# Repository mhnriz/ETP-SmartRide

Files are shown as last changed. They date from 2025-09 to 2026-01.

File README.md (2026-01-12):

# ETP-SmartRide: Smart Transit & Monitoring System
**Status:** Functional Prototype Handed Over
**Date:** January 2026

## 📌 Project Overview
ETP-SmartRide is an IoT-based transit system designed to improve bus efficiency and passenger experience. The system integrates real-time seat occupancy tracking, GPS location monitoring, and a Smart Bus Stop ETA display. 

The project was executed in two phases:
1. **Phase 1 (Planning):** Research, Power Budgeting, and Circuit Drafting.
2. **Phase 2 (Execution):** Hardware integration, ESP-NOW communication, and Firebase Cloud syncing.

## ⚙️ System Architecture
Due to hardware logistics, the current prototype uses a **Modular ESP32 Mesh** rather than a Raspberry Pi master.

* **Master Node (ESP32):** Acts as the Cloud Gateway. It fetches booking data from Firebase via WiFi and broadcasts seat status to nodes.
* **Slave Nodes (ESP32):** Distributed across the bus. Each node manages 4 seats, controlling bi-color LEDs and ultrasonic sensors.
* **Communication:** Internal data is sent via **ESP-NOW** for low-latency, while external data uses **HTTPS/Firebase**.
* **Bus Stop Display:** Uses the same Master circuit to fetch ETA data and output to a 22" monitor.

## 🔋 Hardware & Power Specifications
The system is designed for mobility and sustainability:
- **Power Source:** 100W Monocrystalline Solar Panel [B-18].
- **Storage:** 15AH 12V AGM Solar Battery [B-20].
- **Regulation:** LM2596 Buck-down modules regulated to 5V for logic circuits.
- **Enclosures:** Custom 3D-printed PLA housings.

> **⚠️ HANDOVER NOTE:** All LM2596 buck converters must be verified with a multimeter for stable 5V output before connecting the ESP32 or Pi.

## 📂 Repository Structure
- `/firmware`: Contains `.ino` files for the Bus Master, Bus Stop, and Seat Nodes.
- `/hardware`: Contains the archived KiCad project files (`.zip`) and PDF schematics.
- `/hardware/parts_list.md`: Full Bill of Materials (BOM) with IDs.
- `/docs`: Power budgeting, initial planning documents, and architecture diagrams.
- `HANDOVER.md`: Technical guide for the incoming 8-month team.

## 🚀 Quick Start (Prototype Mode)
1. **Configure WiFi:** Update `ssid` and `password` in the `master_esp32.ino`.
2. **Firebase:** Ensure your `FIREBASE_TOKEN` and URL match your Firestore instance.
3. **Flash Nodes:** Flash the `slave_node.ino` to the respective ESP32s using the MAC addresses listed in the Master code.

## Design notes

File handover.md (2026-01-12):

# 📝 Technical Handover Guide

## 1. Main Unit (Master) Integration
The Main Unit acts as the system Master, responsible for GPS tracking, LTE cloud communication, and managing the RS-485 bus to poll Sensor Nodes.

### ⚙️ Hardware Details
| Component | Function | Hardware Note |
| :--- | :--- | :--- |
| **Raspberry Pi 4** | System Controller | Main logic and UART management. |
| **A7670E Cat-1 HAT** | LTE Module | Cellular data transmission. |
| **NEO-6M GPS** | GPS Receiver | Real-time location tracking. |
| **MAX3485** | RS-485 Transceiver | Communication with Sensor Nodes. |
| **LM2596 Buck** | Power Regulator | Steps down bus voltage (12V) to 5V. |

### ⚠️ Power Logic & Safety
* **Calibration:** The LM2596 must be tuned to exactly **5V** BEFORE connecting to the Raspberry Pi 4.
* **Sensitivity:** The Raspberry Pi is highly sensitive to overvoltage. Always measure output with a multimeter before plugging in the Pi.
* **GPS Fix:** The NEO-6M requires a "Cold Start" which can take several minutes. Ensure the antenna has a clear line of sight to the sky.

---

## 2. Sensor Node (Slave) Integration
Each node monitors 4 seats, processes occupancy locally, and communicates with the Master via RS-485.

### 📊 The Bitmap System
To minimize data traffic, seat status is packed into a single byte (Bitmap):
* **Bit 0 (1):** Seat 1 (or 5, 9, etc.)
* **Bit 1 (2):** Seat 2
* **Bit 2 (4):** Seat 3
* **Bit 3 (8):** Seat 4
* **Example:** If Master sends `0110`, Seats 2 and 3 are marked as Booked.

### 📍 Pinout Reference (ESP32)
| Component | ESP32 Pin | Function | Hardware Note |
| :--- | :--- | :--- | :--- |
| **MAX3485 RO** | GPIO 17 | RXD2 | Connect to Receiver Output. |
| **MAX3485 DI** | GPIO 16 | TXD2 | Connect to Driver Input. |
| **MAX3485 RE/DE**| GPIO 2 | EN (Direction) | HIGH = Transmit, LOW = Receive. |
| **VL53L0X SDA** | GPIO 21 | I2C Data | All sensors share this line. |
| **VL53L0X SCL** | GPIO 22 | I2C Clock | All sensors share this line. |
| **XSHUT 1** | GPIO 18 | Reset 1 | Used to assign Address 0x30. |
| **XSHUT 2** | GPIO 19 | Reset 2 | Used to assign Address 0x31. |

---

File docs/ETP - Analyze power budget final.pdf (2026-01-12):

# Operating Scenario:

- 7AM to 7PM (12 operating hours)
- At least 5 total hours of sunlight
- based on local solar radiation data at UTP, Perak (Reference) (https://utpedia.utp.edu.my/id/eprint/13641/1/Final%20Dissertation.pdf)
- Assume solar power unit efficiency at 65%
- All component runs at 5V*

# Component Operating Characteristics for bus unit:

## RASPBERRY PI 4:

- Always active
- Estimated current: 1A

A7670E:
- TX every 10 seconds, assume TX takes 1 secs
- Estimated current:
- Idle: mA for 9 secs
- Active: 500mA for 1 secs
- Rare case: 2A, handle by 2200µ 25V capacitor
- Average: 77mA
- Reference (Section 5.4) (https://nostris.ee/pdf/A7670%20Series%20Hardware%20Design_V1.00.pdf)

## NodeMCU ESP-32:

- Always active
- Estimated current: 53mA
- Reference (Section 5.4) (https://www.espressif.com/sites/default/files/documentation/esp32_datasheet_en.pdf)

## Xiaomi Redmi Monitor RMMNT215NF:

- Always active
- current: 2A
- Voltage: 12A
- Reference (Similar product) (https://www.manualslib.com/manual/3883141/Xiaomi-Rmmnt27nf.html?page=12#manual)

## SFM-27 BUZZER:

- Active during bus stop, assume 2 minutes every 5 minutes, 4 pieces
- Always active
- Estimated current: 6mA
- Reference (Product descripton) (https://shopee.com.my/Buzzer-with-Wire-3-24V-SFM-27-2312-%28Continuous-Sound-Intermittent-Sound%29-i.82137098.11625621562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)

## NEO-6m:

- Always active
- Estimated current: 70mA
- Reference (Section 3.3) (https://content.u-blox.com/sites/default/files/products/documents/NEO-6_DataSheet_%28GPS.G6-HW-09005%29.pdf)

## MAX485:

- Always active
- Estimated current: 1.6mA

## MH-ET LIVE Scanner v3.0:

- Always active
- Estimated current: 20mA

## LED light:

- Active during bus stop, assume 2 minutes every 5 minutes, 4 pieces
- Estimated current:
- Active: 80mA (4 × 20mA) for 2 minutes
- Average:32mA
- Reference (Product description) (https://shopee.com.my/100PCS-LED-3mm-5mm-Round-Diffused-Matte-Water-Clear-Red-Blue-Green-Two-Color-Common-Anode-Cathode-LED-Diode-Light-Emitting-Diode-i.12432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)

## ToF sensor VL53L0XV2:

- Active during bus stop, assume 2 minutes every 5 minutes, 4 pieces (seat)+ 1 at door
- Estimated current:
- Active: 675mA (45 × 15 mA)
- Average: 270mA

# Component Operating Characteristics for bus stop unit:

## RASPBERRY PI 4:

- Always active
- Estimated current: 1A

A7670E:
- TX every 10 seconds, assume TX takes 1 secs
- Estimated current:
- Idle: mA for 9 secs
- Active: 500mA for 1 secs
- Rare case: 2A, handle by 2200µ 25V capacitor
- Average: 77mA
- Reference (Section 5.4) (https://nostris.ee/pdf/A7670%20Series%20Hardware%20Design_V1.00.pdf)

## Xiaomi Redmi Monitor RMMNT215NF:

- Always active
- current: 2A
- Voltage: 12A
- Reference (Similar product) (https://www.manualslib.com/manual/3883141/Xiaomi-Rmmnt27nf.html?page=12#manual)

# Daily Energy Consumption Estimate:

Module | Avg Current (mA) | Voltage (V) | Daily Runtime (h) | Energy (Wh/Day)
Bus Stop Unit | 3077 | 5 | 12 | 184.6
Bus Unit | 3291 | 5 | 12 | 197.3
Total | 6368 | 5 | 12 | 381.9

# Solar Power System Feasibility:

## Solar Panel:

- Maximum Power: 100W
- Voltage at Maximum Power: 18V
- Current at Max power: 5.56A
- Reference (Product description) (https://shopee.com.my/POWERMAS-20-Watt-20W-Monocrystalline-A-Grade-Solar-Panel-(Ready-Stock)-i.988475493.22643540091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)

## Estimated Daily Energy Harvest:

At 65% efficiency:
100W ×

65
100 × 5ℎ = 325Wℎ/day

## Battery:

- Bus unit:
- Total capacity: 15Ah 12 V nominal
- Bus stop unit
- Total capacity: 15mAh 12 V nominal

## System Analysis Conclusion:

Module | Daily energy need | Solar daily harvest | Daily Surplus | Battery capacity | Backup runtime (battery only)
Bus Unit | 197.3 Wh | 325 Wh | +127.7 Wh | 180 Wh | 0.91 days
Bus Stop Unit | 184.6 Wh | 325 Wh | +140.4 Wh | 180 Wh | 0.98 days

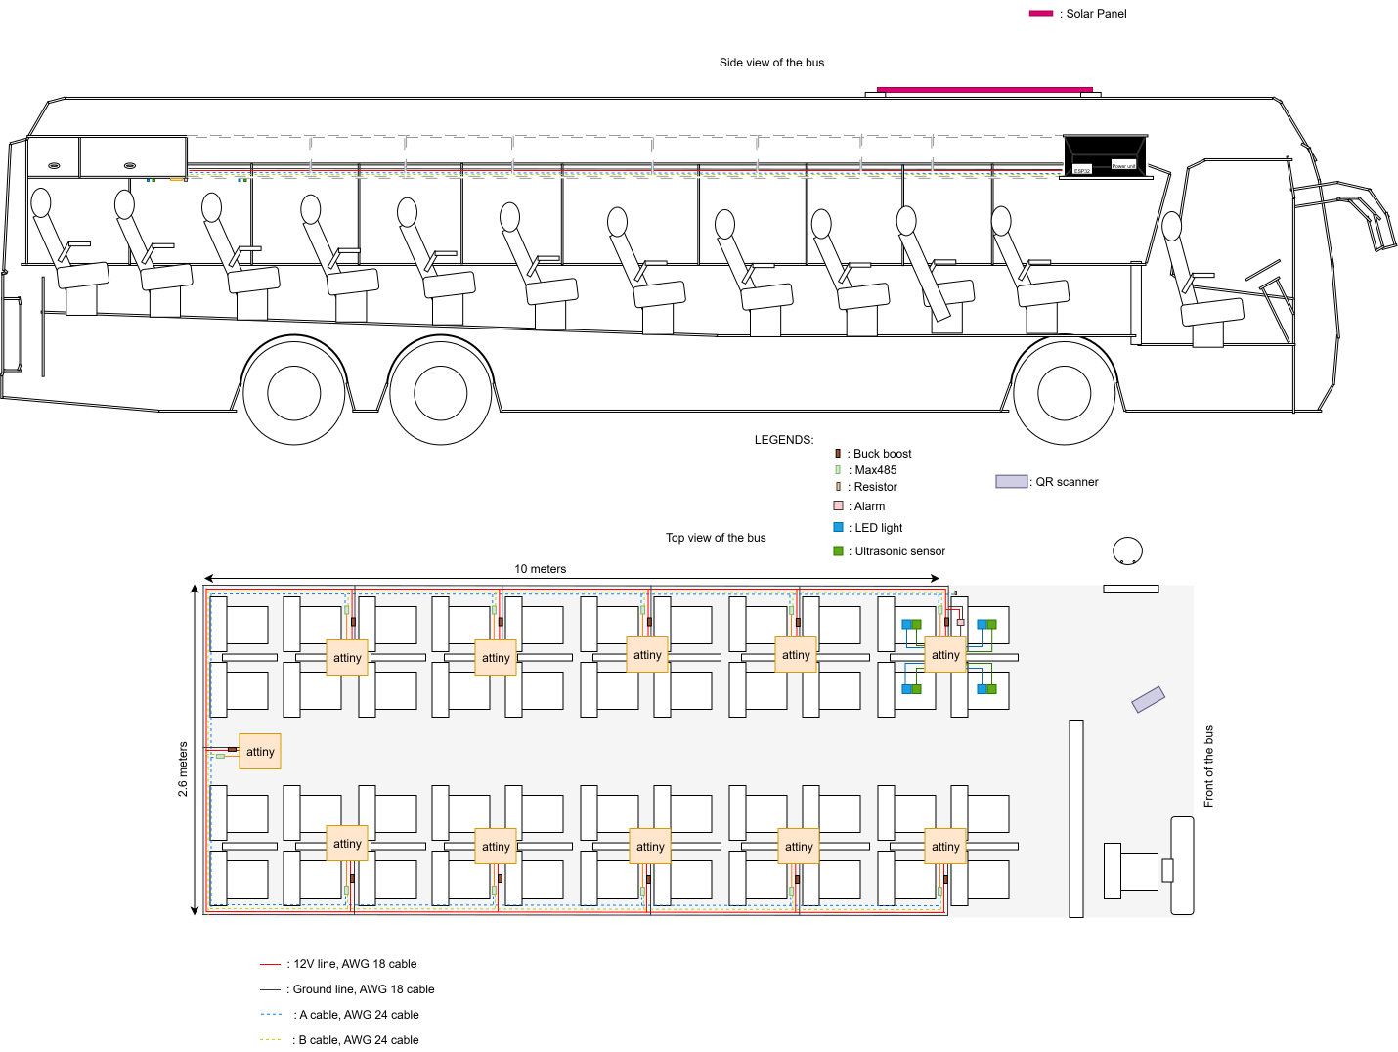
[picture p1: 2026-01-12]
docs/Bus_layout _overview.png

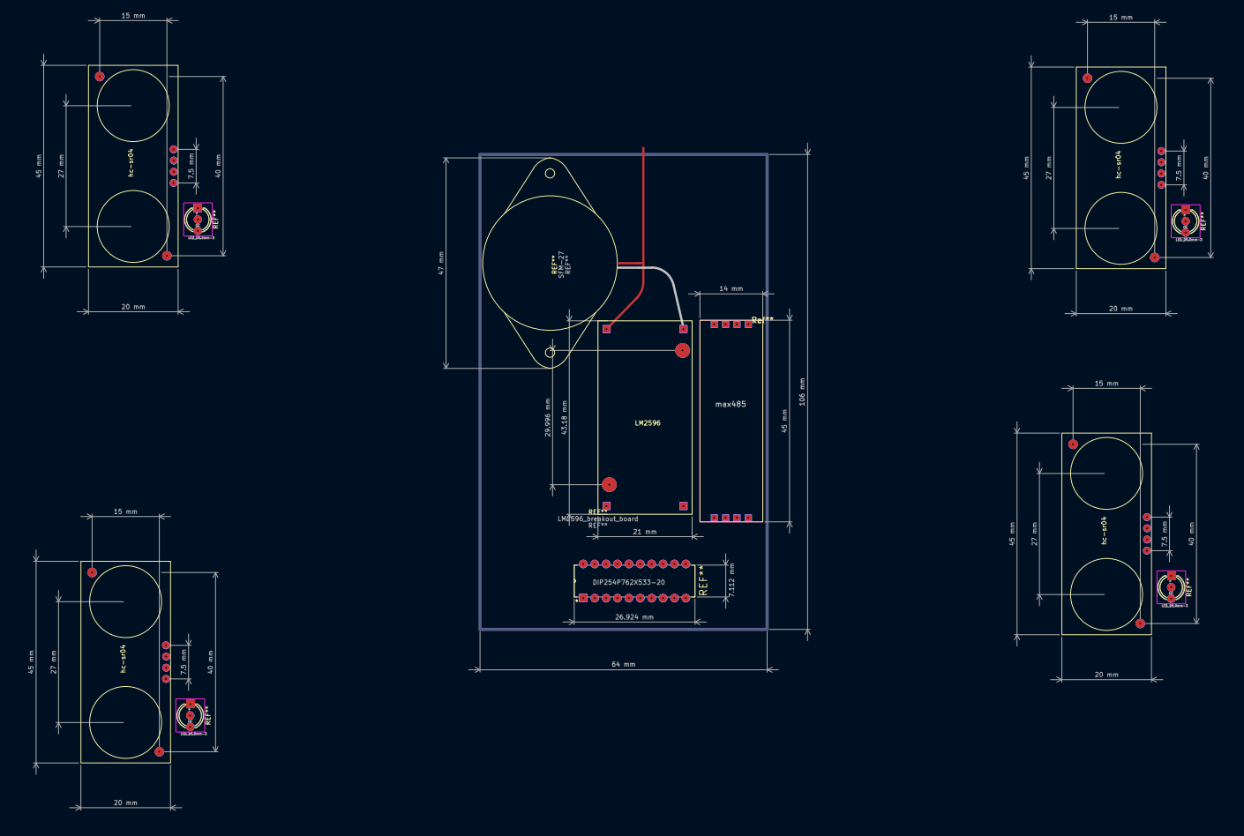
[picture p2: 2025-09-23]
hardware/bus_seat_unit/layout.png

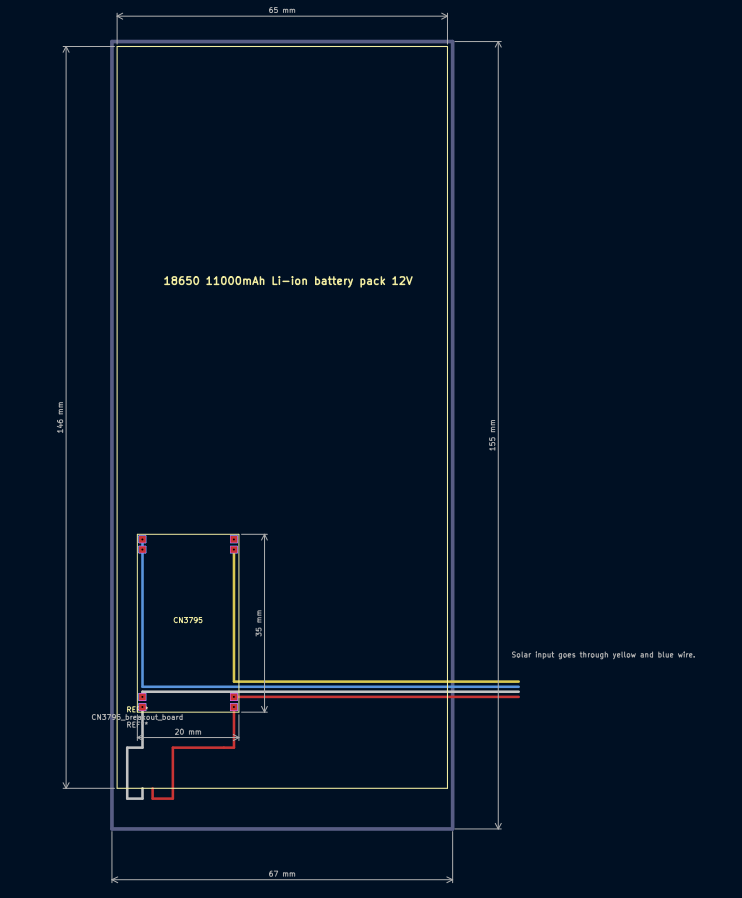
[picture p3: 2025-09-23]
hardware/bus_power_unit/layout.png

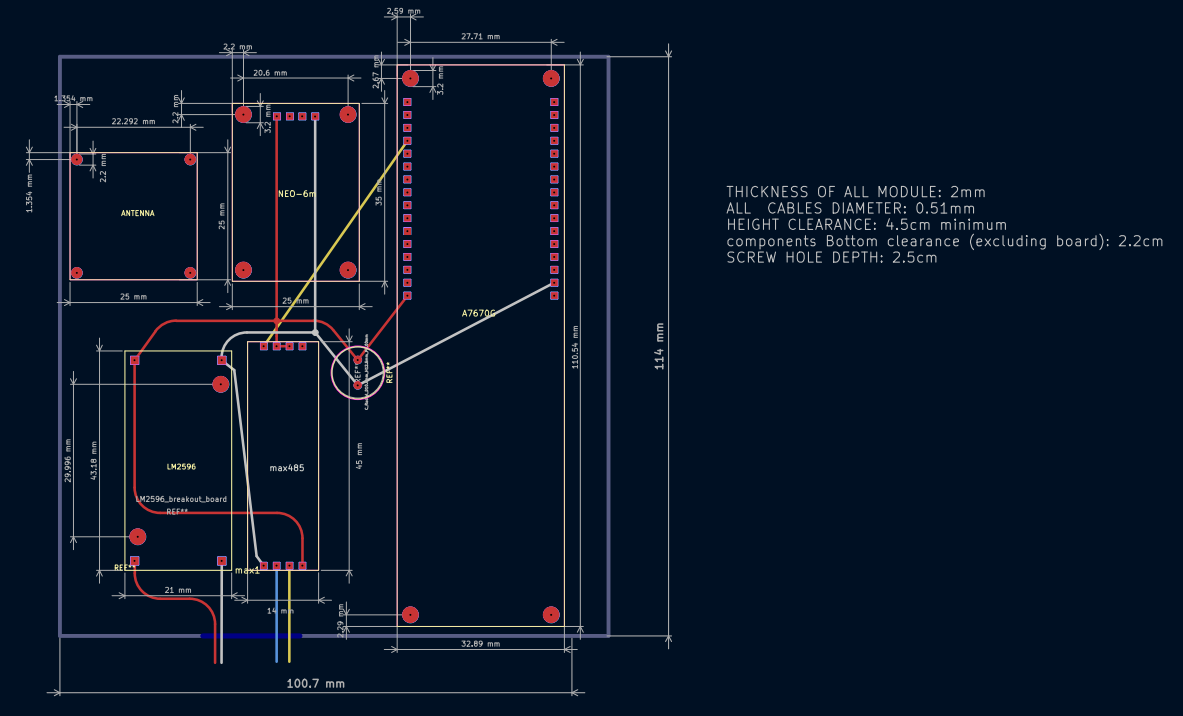
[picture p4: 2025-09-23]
hardware/bus_main_unit/layout.png

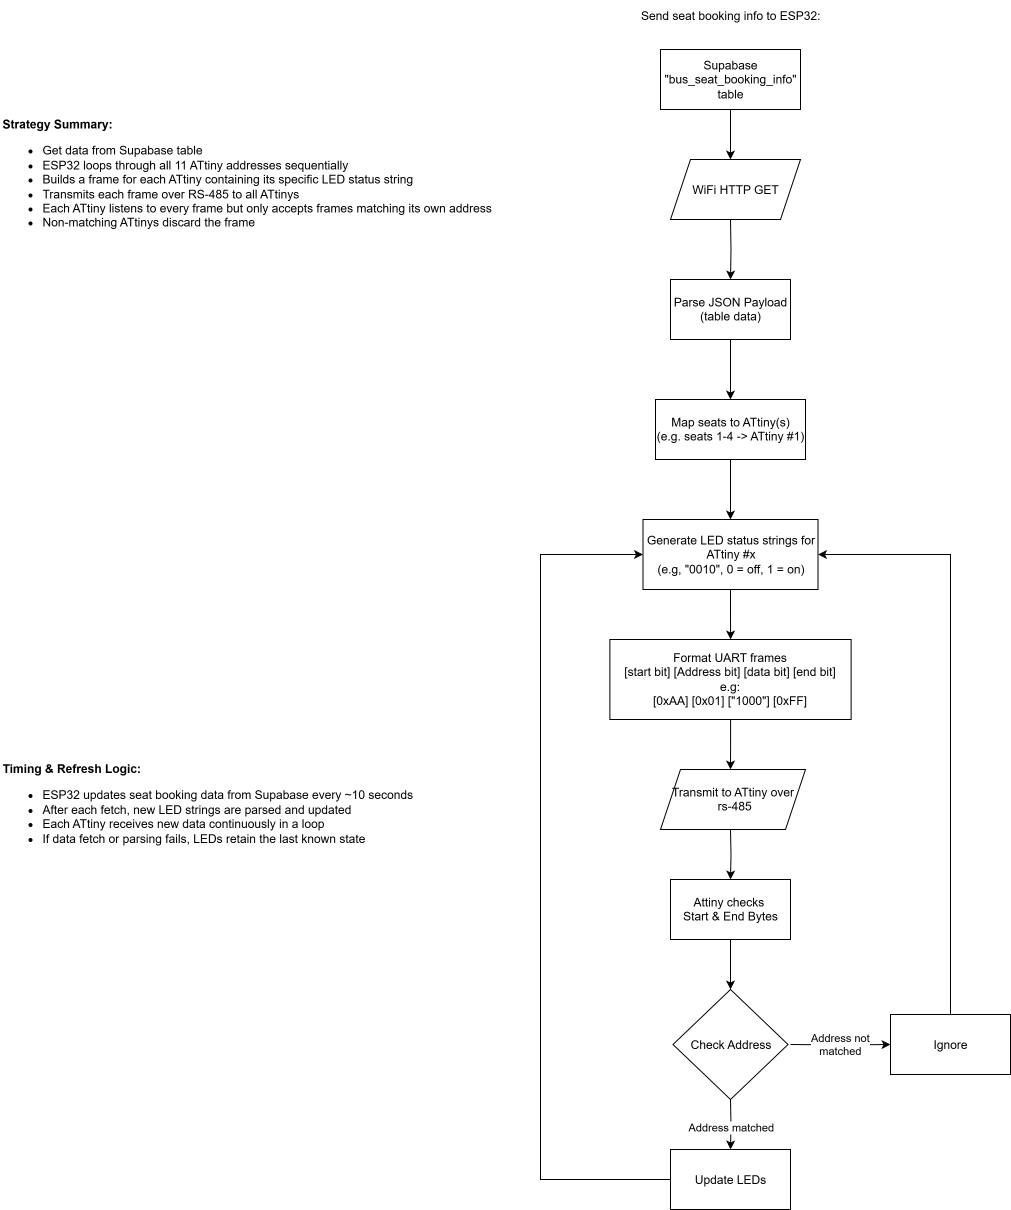
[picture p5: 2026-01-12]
docs/Bus_Unit_Code_logics_flowchart.png

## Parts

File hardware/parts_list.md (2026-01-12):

## 1. Processing & Connectivity
| ID | Name and Model | Description | Quantity |
| :--- | :--- | :--- | :--- |
| **B-01** | NodeMCU ESP-32 (CH340) | Main CPU for Master, Slave nodes, and Bus Stop units. | 2 |
| **-** | Raspberry Pi 4 Model B | Main CPU for data collection & cloud transmission (Handover Target). | 3 |
| **B-13** | SIM Module A7670E Cat-1 | Provides onboard LTE internet connection via IoT SIM. | 3 |
| **B-07** | GPS Module GY NEO 6M | Provides GPS location capabilities for the bus. | 4 |
| **B-11** | IoT M2M SIM Card | Cellular data provider for GPS and Cloud sync. | 4 |
| **B-09** | RS485 to TTL (MAX3485) | Differential communication between Pi and ESP32. | 4 |
| **-** | SD card 16 GB A1 | Storage for Raspberry Pi OS and logs. | 3 |

## 2. Sensing & Interaction
| ID | Name and Model | Description | Quantity |
| :--- | :--- | :--- | :--- |
| **B-03** | ToF Sensor (VL53L0X) | High-accuracy infrared distance sensing for seat occupancy. | 8 |
| **B-02** | 5mm RG LED (Common Cathode) | Bi-color seat availability indicators (Red/Green). | 10 |
| **BS-02** | MH-ET LIVE Scanner v3.0 | QR code scanner for ticket/boarding validation. | 1 |
| **B-04** | 12V Buzzer SFM 27 | Audible alert for seat violations or system status. | 6 |
| **B-14** | 22" Flat Monitor (75Hz) | ETA Display for the Smart Bus Stop. | 3 |
| **-** | Ultrasonic Sensors | Temporary seat sensors used during prototype execution. | 8 |

## 3. Power Management (Solar & Regulation)
| ID | Name and Model | Description | Quantity |
| :--- | :--- | :--- | :--- |
| **B-18** | Monocrystalline Panel 100W | 18V Solar panel for renewable energy. | 3 |
| **B-19** | MPPT Controller BL-30A | Manages charging between solar panel and battery. | 3 |
| **B-20** | Solar Battery 15AH 12V | AGM battery for energy storage. | 3 |
| **B-10** | Buck-boost XL6009 | Provides stable 12V output for buzzers/monitors. | 4 |
| **B-21** | Buck-down LM2596 | Steps 12V battery voltage down to 5V for ESP32/Pi. | 8 |
| **B-16** | Capacitor 2200 µF | Electrolytic capacitor for voltage stability. | 10 |
| **B-17** | MLCC 0.1 µF | Decoupling capacitor for voltage stability. | 10 |

## 4. Discrete Electronics & Accessories
| ID | Name and Model | Description | Quantity |
| :--- | :--- | :--- | :--- |
| **B-05** | Transistor BJT 2N2222 | Switching driver for buzzers and high-current LEDs. | 9 |
| **B-06** | Resistor 1kΩ | Current limiting for BJT base protection. | 10 |
| **B-15** | DC barrel jack AWG18 | Power input pigtail for monitors. | 4 |
| **B-22** | Portable TV Stand | Mounting hardware for the ETA Display monitors. | 2 |
| **-** | Micro HDMI to HDMI | Connection cable for Pi 4 to Monitor. | 3 |
| **-** | Filament PLA | Material for 3D printed enclosures. | 2 |

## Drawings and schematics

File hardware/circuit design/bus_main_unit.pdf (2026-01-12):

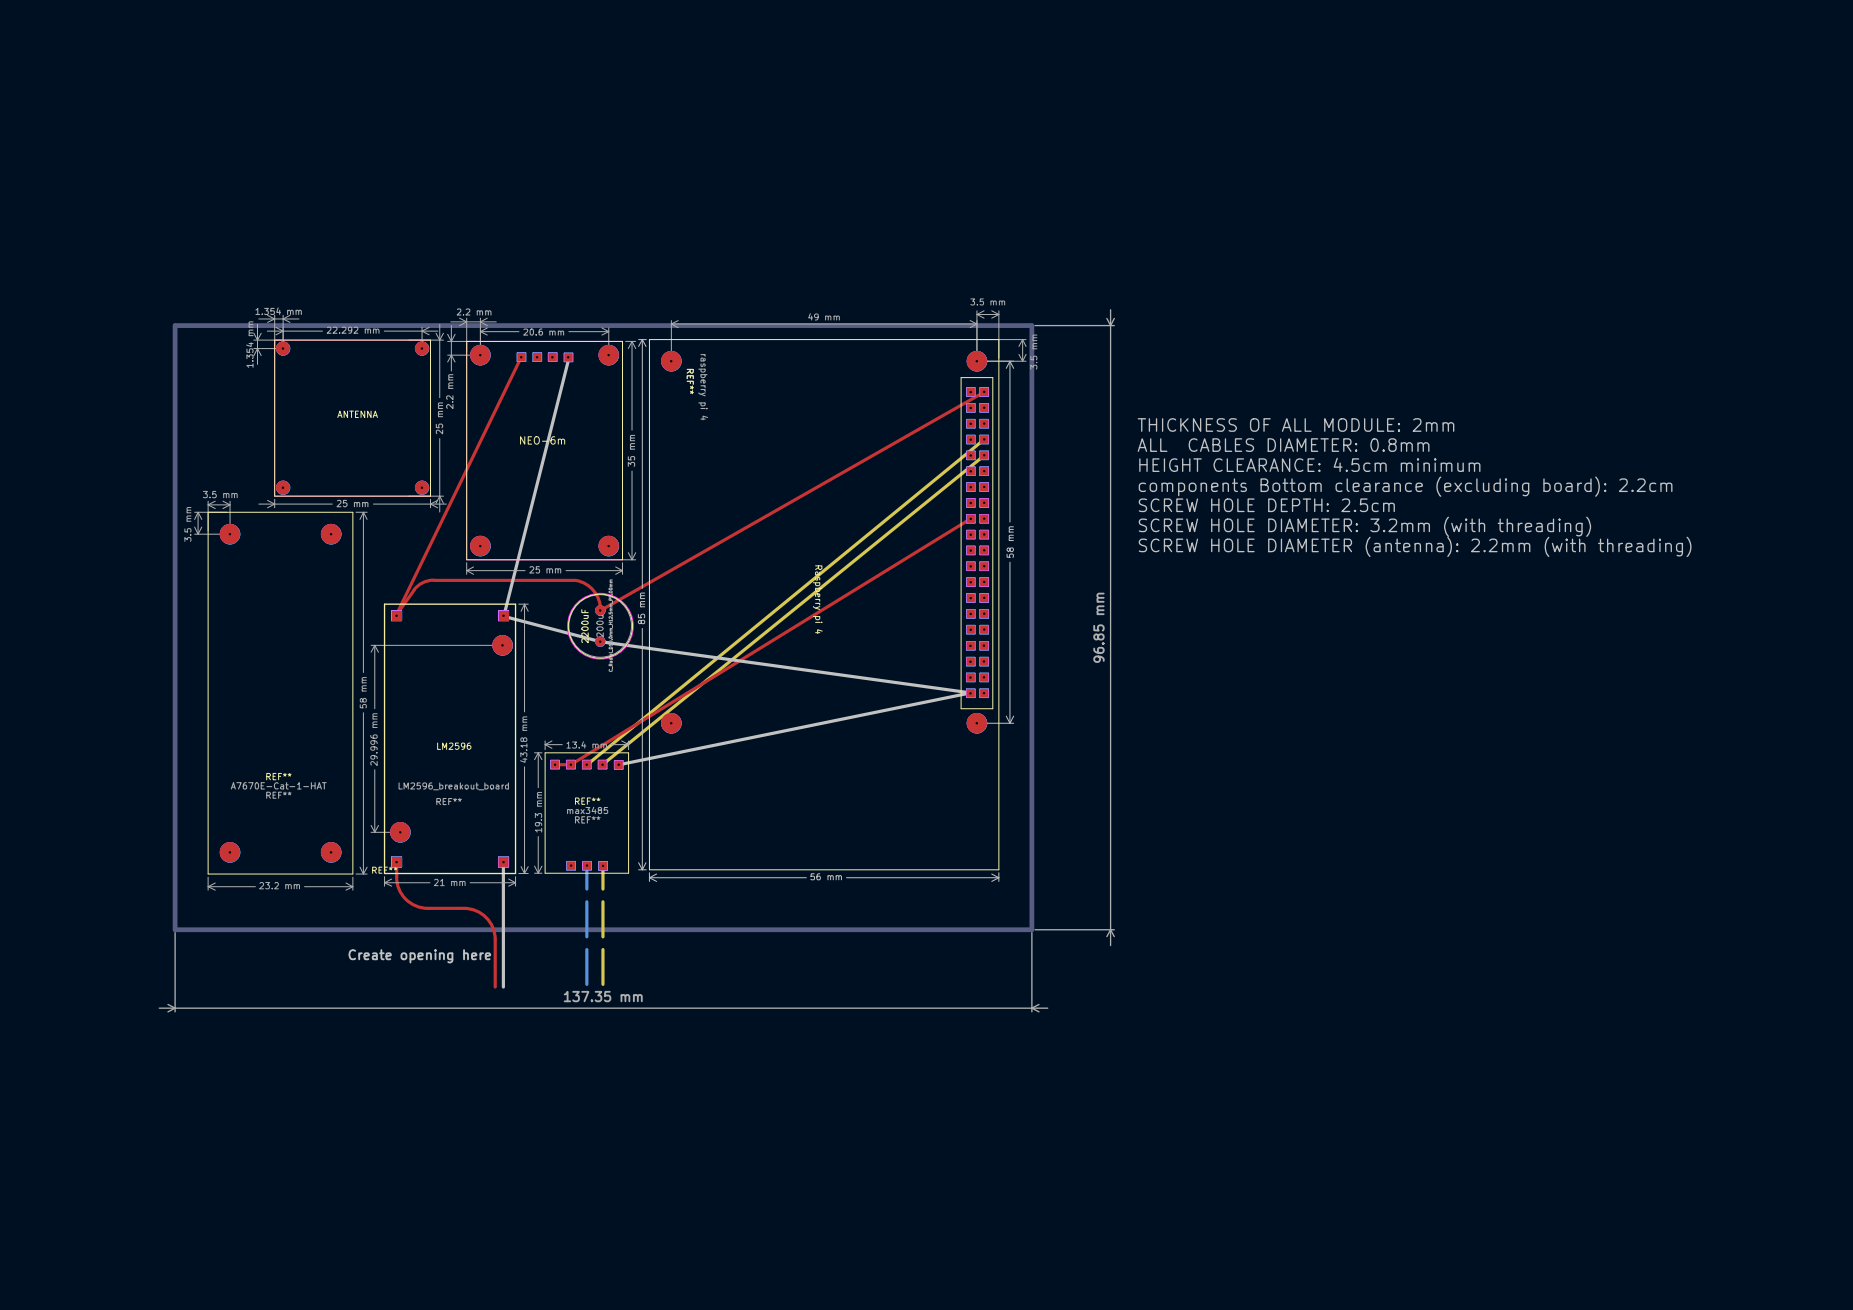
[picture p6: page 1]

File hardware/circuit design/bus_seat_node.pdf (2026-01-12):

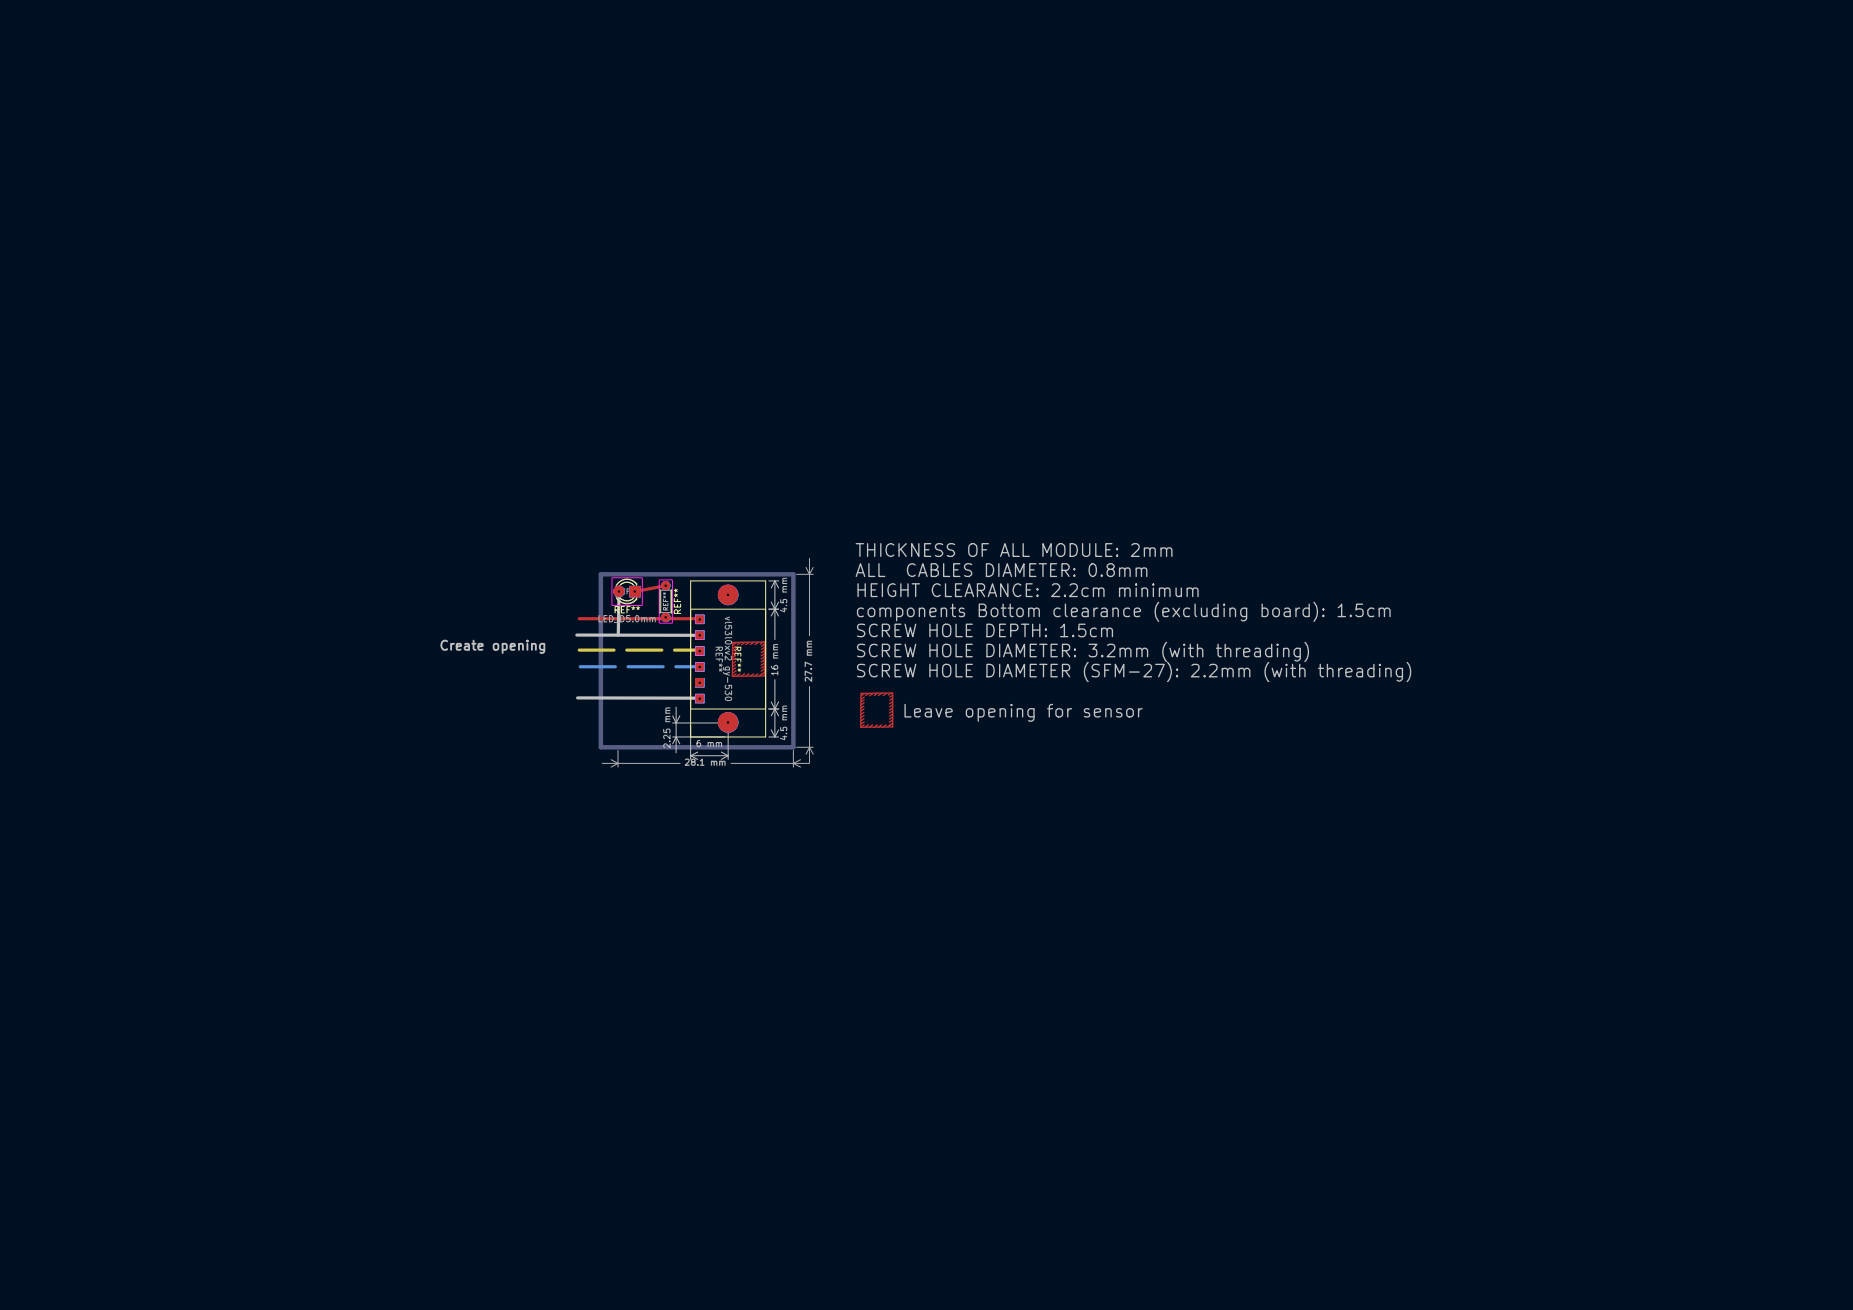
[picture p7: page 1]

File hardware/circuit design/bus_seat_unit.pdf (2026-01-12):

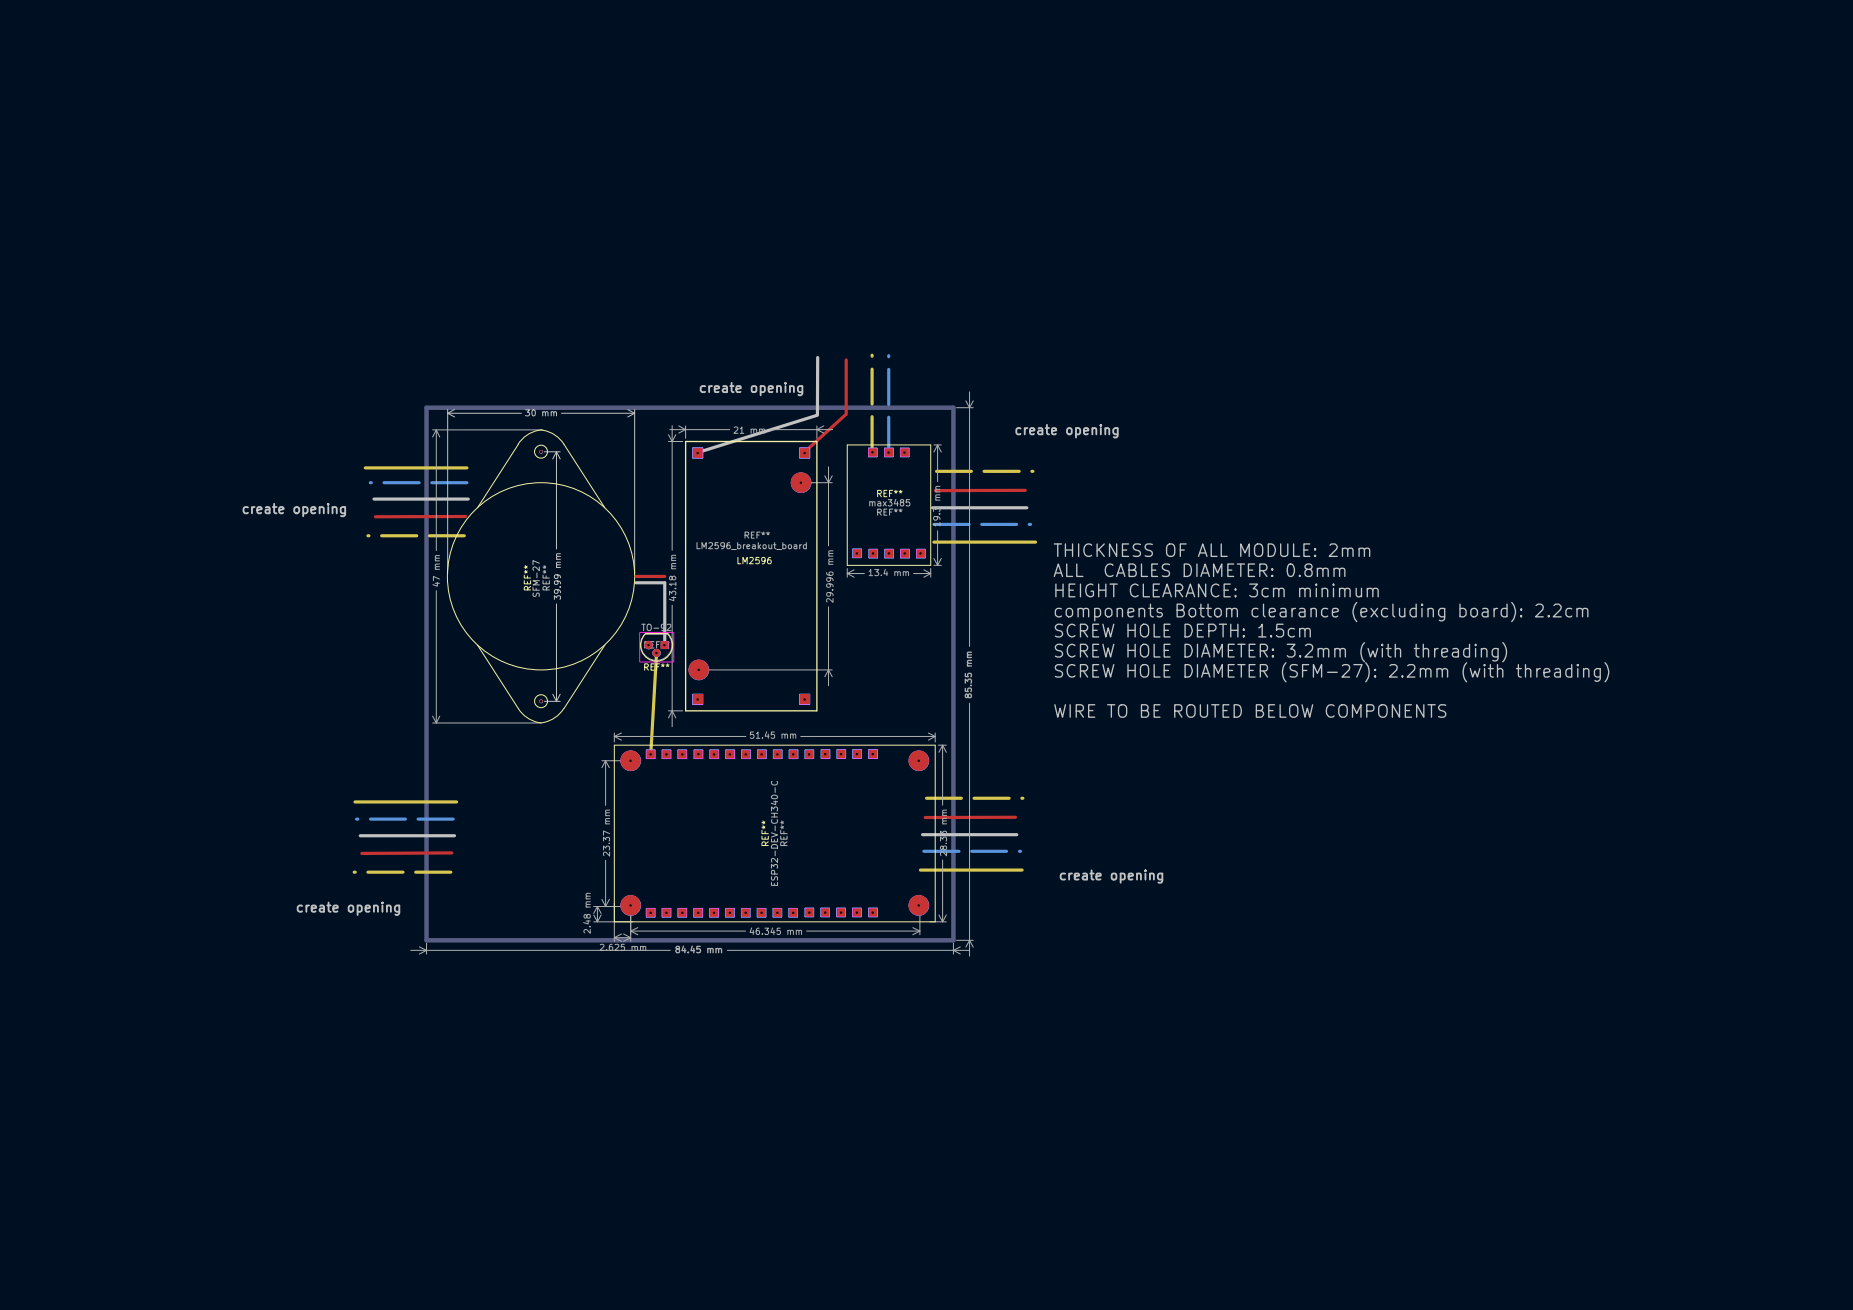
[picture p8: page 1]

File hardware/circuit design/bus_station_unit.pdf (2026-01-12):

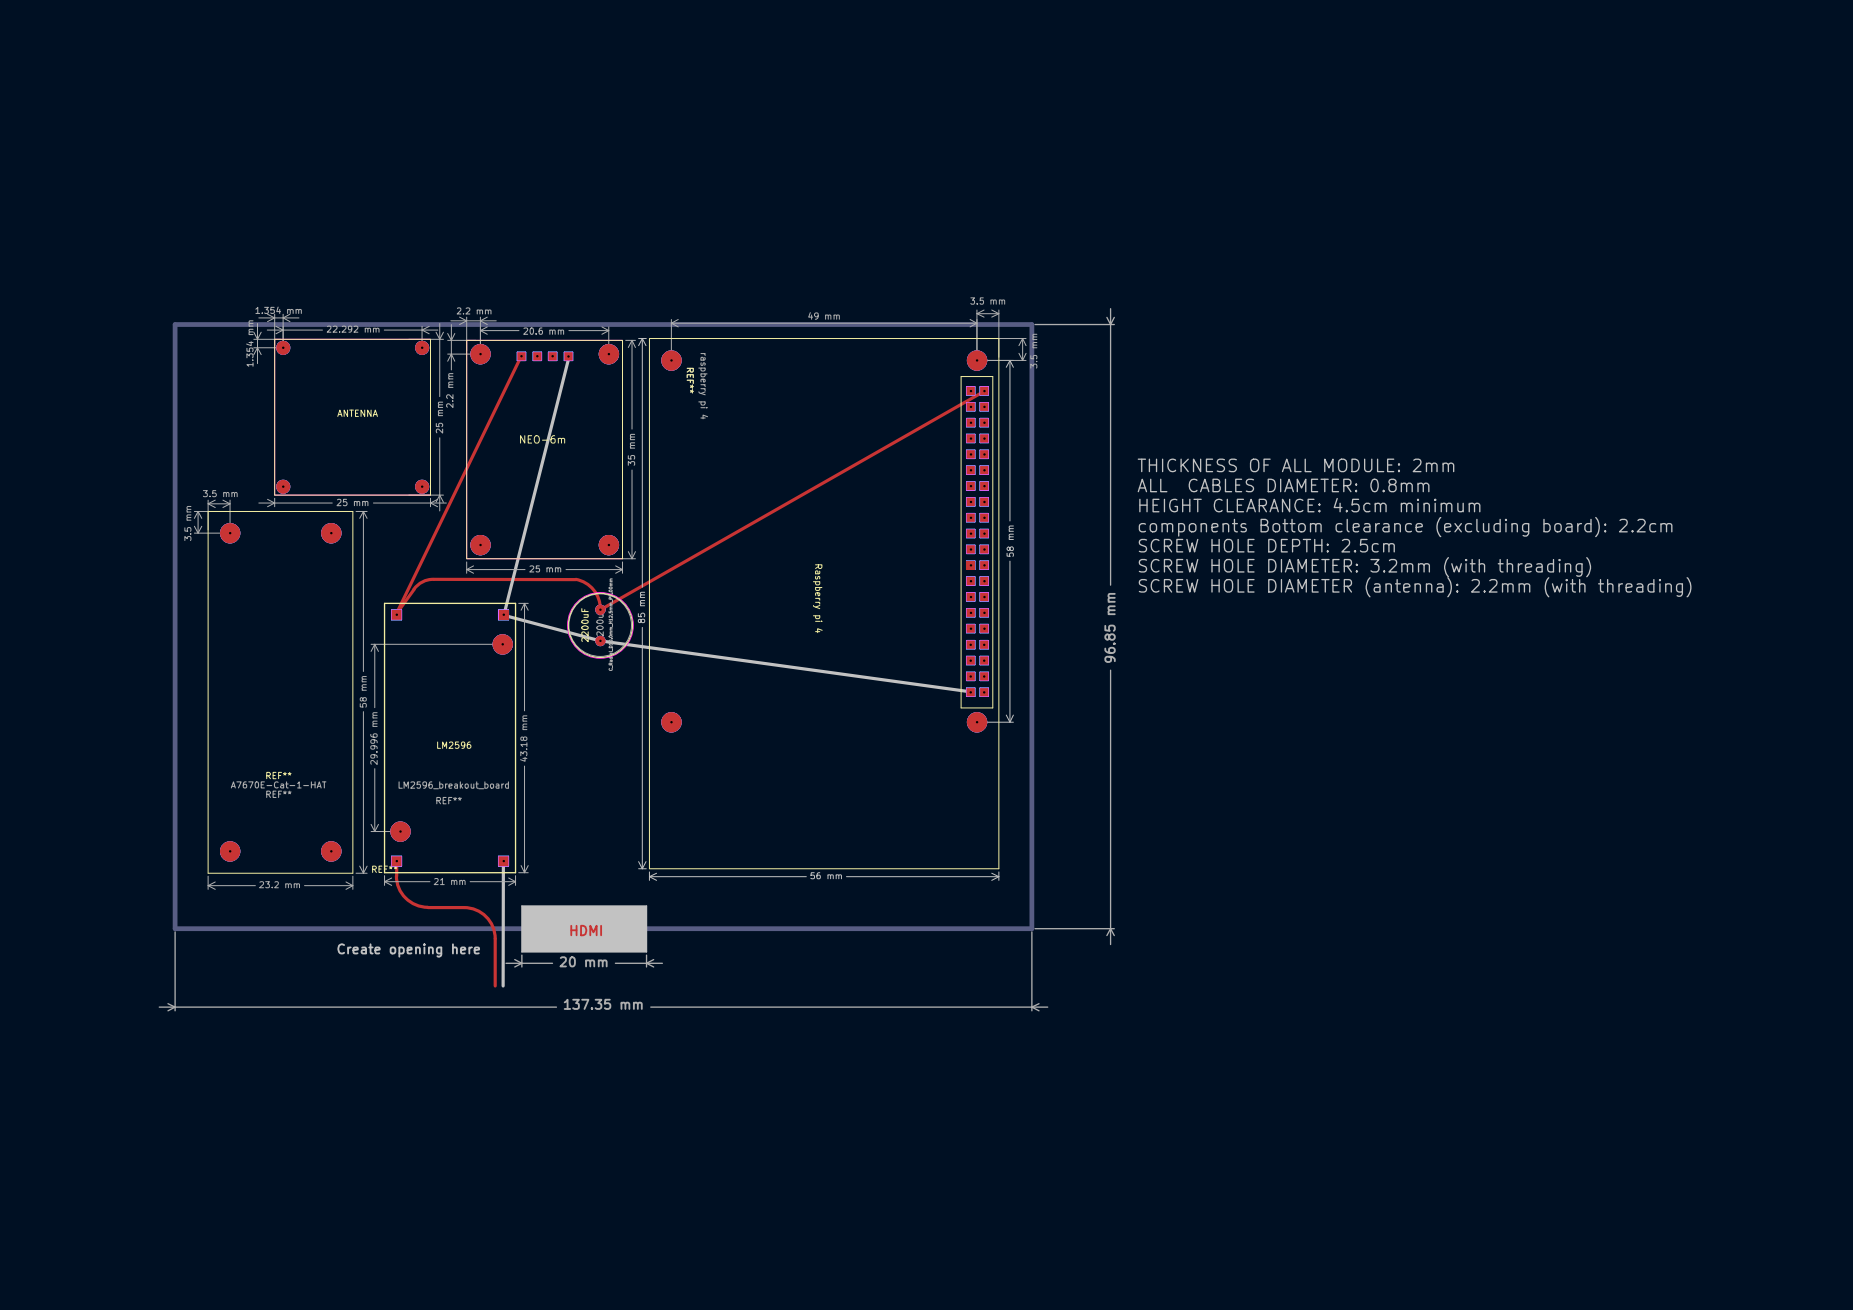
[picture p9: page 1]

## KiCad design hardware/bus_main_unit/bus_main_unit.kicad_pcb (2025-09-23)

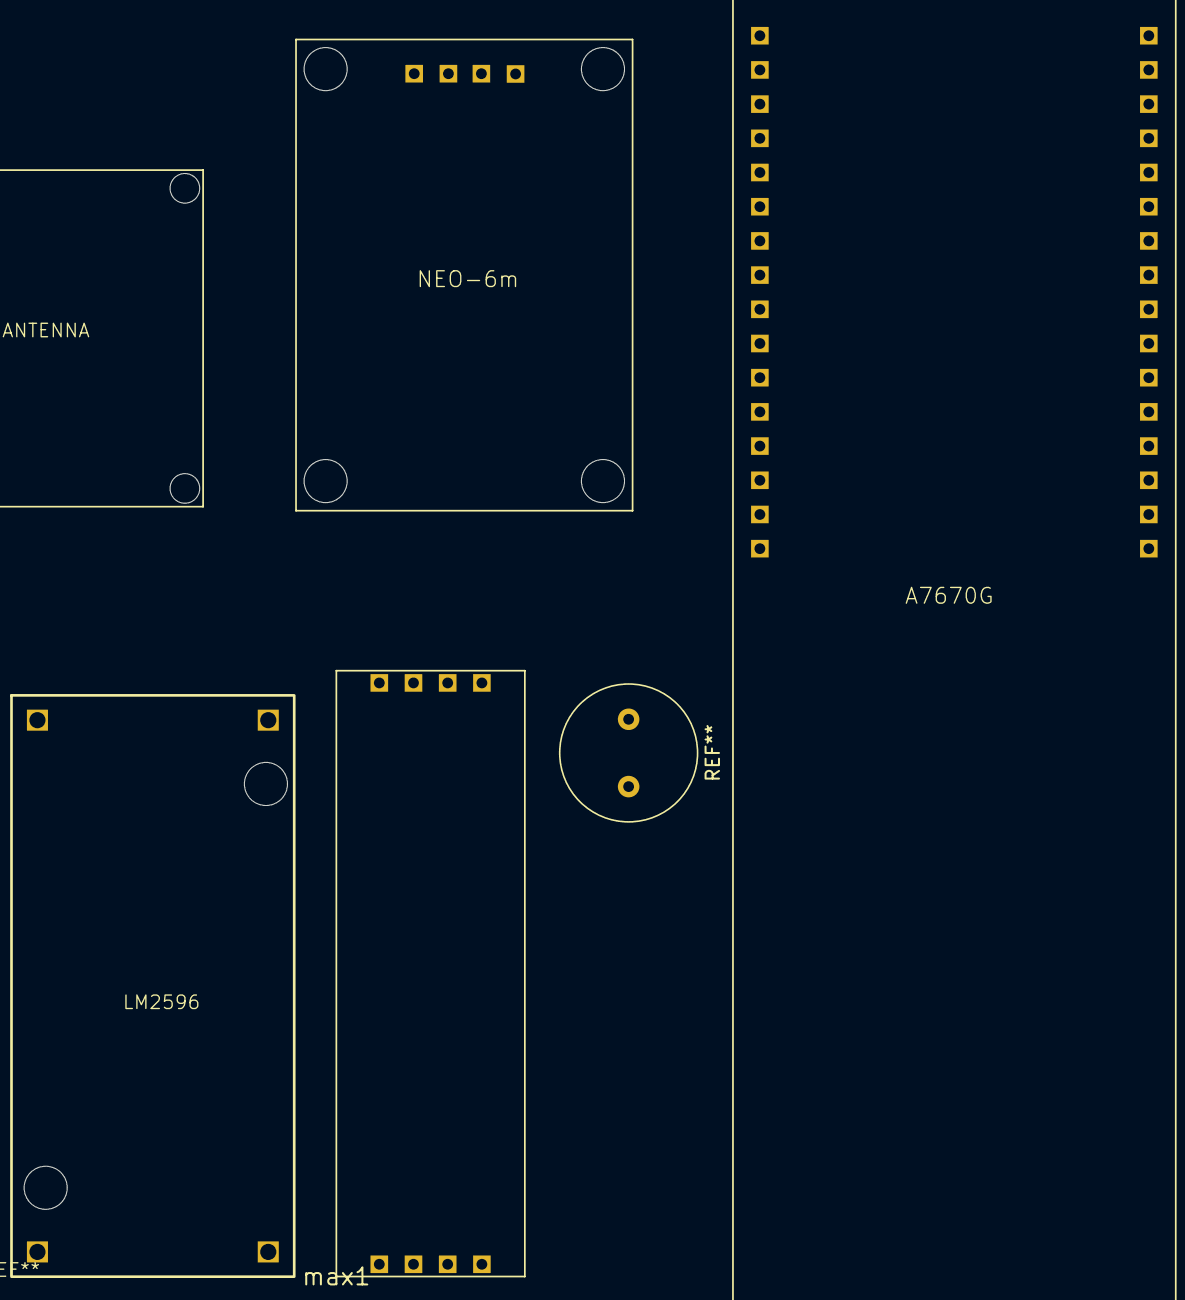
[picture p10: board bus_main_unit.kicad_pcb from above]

Board: 2 copper layers, 4 parts (0 on the bottom side), 5 nets, no tracks yet.

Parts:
A1: A7670G
antenna1: ANTENNA
max1: max485
neo-6m1: NEO-6m_breakout_board

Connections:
unnamed: A1.33, max1.DI
unnamed: A1.RXD, neo-6m1.TX
unnamed: A1.TXD, neo-6m1.RX
unnamed: A1.VBAT, max1.DE, max1.RE, max1.VCC, neo-6m1.VCC
unnamed: max1.GND, neo-6m1.GND

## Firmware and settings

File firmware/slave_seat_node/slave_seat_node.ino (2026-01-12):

#include <esp_now.h>
#include <WiFi.h>
#include <esp_wifi.h>

// ------------------- Node Config -------------------
// Buzzer
#define BUZZER_PIN 4

// Each seat bi-color LED (common GND)
#define LED1_R 12
#define LED1_G 13
#define LED2_R 14
#define LED2_G 15
#define LED3_R 16
#define LED3_G 17
#define LED4_R 18
#define LED4_G 19

// Ultrasonic sensors: trig / echo
#define US1_TRIG 21
#define US1_ECHO 25
#define US2_TRIG 23
#define US2_ECHO 22
#define US3_TRIG 26
#define US3_ECHO 27
#define US4_TRIG 32
#define US4_ECHO 33

// Threshold distance (cm) — below this means someone is sitting
#define OCCUPIED_DIST 30

uint8_t bitmap = 0;

// ------------------- Helper Functions -------------------
float getDistanceCM(int trigPin, int echoPin) {
  digitalWrite(trigPin, LOW);
  delayMicroseconds(2);
  digitalWrite(trigPin, HIGH);
  delayMicroseconds(10);
  digitalWrite(trigPin, LOW);

  long duration = pulseIn(echoPin, HIGH, 30000);  // timeout 30ms
  float distance = duration * 0.0343 / 2;         // convert to cm
  return distance > 0 ? distance : 999;           // return large value if timeout
}

void updateSeatLEDs(uint8_t bits) {
  digitalWrite(LED1_R, bits & 0x01 ? HIGH : LOW);
  digitalWrite(LED1_G, bits & 0x01 ? LOW : HIGH);
  digitalWrite(LED2_R, bits & 0x02 ? HIGH : LOW);
  digitalWrite(LED2_G, bits & 0x02 ? LOW : HIGH);
  digitalWrite(LED3_R, bits & 0x04 ? HIGH : LOW);
  digitalWrite(LED3_G, bits & 0x04 ? LOW : HIGH);
  digitalWrite(LED4_R, bits & 0x08 ? HIGH : LOW);
  digitalWrite(LED4_G, bits & 0x08 ? LOW : HIGH);
}

void onDataReceive(const esp_now_recv_info_t *info, const uint8_t *data, int len) {
  if (len != 1) return;  // Expect 1 byte (4 seats)
  bitmap = data[0];

  Serial.printf("Received bitmap: %02X from %02X:%02X:%02X:%02X:%02X:%02X\n",
                bitmap,
                info->src_addr[0], info->src_addr[1], info->src_addr[2],
                info->src_addr[3], info->src_addr[4], info->src_addr[5]);

  updateSeatLEDs(bitmap);
}

void checkSeatOccupancy() {
  // Read ultrasonic distances
  float d1 = getDistanceCM(US1_TRIG, US1_ECHO);
  float d2 = getDistanceCM(US2_TRIG, US2_ECHO);
  float d3 = getDistanceCM(US3_TRIG, US3_ECHO);
  float d4 = getDistanceCM(US4_TRIG, US4_ECHO);

  bool alert = false;

  // Check if a booked seat is physically occupied
  if ((bitmap & 0x01) && d1 < OCCUPIED_DIST) alert = true;
  if ((bitmap & 0x02) && d2 < OCCUPIED_DIST) alert = true;
  if ((bitmap & 0x04) && d3 < OCCUPIED_DIST) alert = true;
  if ((bitmap & 0x08) && d4 < OCCUPIED_DIST) alert = true;

  if (alert) {
    digitalWrite(BUZZER_PIN, HIGH);
    Serial.println("⚠️  Someone sitting on a booked seat!");
  } else {
    digitalWrite(BUZZER_PIN, LOW);
  }

  Serial.printf("Distances: %.1f, %.1f, %.1f, %.1f cm\n", d1, d2, d3, d4);
}

// ------------------- Setup -------------------
void setup() {
  Serial.begin(115200);

  // LED setup
  pinMode(LED1_R, OUTPUT); pinMode(LED1_G, OUTPUT);
  pinMode(LED2_R, OUTPUT); pinMode(LED2_G, OUTPUT);
  pinMode(LED3_R, OUTPUT); pinMode(LED3_G, OUTPUT);
  pinMode(LED4_R, OUTPUT); pinMode(LED4_G, OUTPUT);

  // Ultrasonic setup
  pinMode(US1_TRIG, OUTPUT); pinMode(US1_ECHO, INPUT);
  pinMode(US2_TRIG, OUTPUT); pinMode(US2_ECHO, INPUT);
  pinMode(US3_TRIG, OUTPUT); pinMode(US3_ECHO, INPUT);
  pinMode(US4_TRIG, OUTPUT); pinMode(US4_ECHO, INPUT);

  // Buzzer setup
  pinMode(BUZZER_PIN, OUTPUT);
  digitalWrite(BUZZER_PIN, LOW);

  // WiFi + ESP-NOW
  WiFi.mode(WIFI_STA);
  esp_wifi_set_channel(6, WIFI_SECOND_CHAN_NONE); // Match master's channel

  if (esp_now_init() != ESP_OK) {
    Serial.println("ESP-NOW init failed!");
    while (true);
  }

  esp_now_register_recv_cb(onDataReceive);

  updateSeatLEDs(0x00);  // all green initially
}

// ------------------- Loop -------------------
void loop() {
  checkSeatOccupancy();
  delay(1000); // check every 1s
}

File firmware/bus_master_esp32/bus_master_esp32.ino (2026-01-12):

#include <WiFi.h>
#include <WiFiClientSecure.h>
#include <HTTPClient.h>
#include <esp_now.h>
#include <ArduinoJson.h>
#include <esp_wifi.h>


// ------------------- WiFi & Firebase -------------------
const char* ssid = "ssid";
const char* password = "password";
const char* FIREBASE_TOKEN = "firebase_api_token";
const char* FIREBASE_URL = "https://firestore.googleapis.com/v1/projects/utpsmartride-db/databases/(default)/documents/buses/Bus%20A/seats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";

// ------------------- ESP-NOW Nodes -------------------
uint8_t NODE_MACS[][6] = {
  {0x28,0x05,0xA5,0x6E,0x63,0x4C}, // Node 1
  {0x28,0x05,0xA5,0x70,0x8F,0x14}  // Node 2
};
const int NUM_NODES = sizeof(NODE_MACS)/6;

// ------------------- Functions -------------------
void sendBitmap(uint8_t* mac, uint8_t bitmap){
  esp_err_t result = esp_now_send(mac, &bitmap, sizeof(bitmap));
  if(result == ESP_OK){
    Serial.printf("Sent bitmap %02X to node\n", bitmap);
  } else {
    Serial.printf("Error sending bitmap %02X\n", bitmap);
  }
}

void setup() {
  Serial.begin(115200);

  // Connect WiFi
  WiFi.mode(WIFI_AP_STA);
  WiFi.begin(ssid, password);

  // Wait for connection
  while (WiFi.status() != WL_CONNECTED) {
    delay(500);
    Serial.print(".");
  }
  Serial.println("Connected!");

  // Lock ESP-NOW to the same channel
  uint8_t wifi_channel = WiFi.channel();
  esp_wifi_set_channel(wifi_channel, WIFI_SECOND_CHAN_NONE);
  Serial.printf("ESP-NOW set to channel %d\n", wifi_channel);

  // Init ESP-NOW
  if(esp_now_init() != ESP_OK){
    Serial.println("ESP-NOW init failed"); while(true);
  }

  for(int i=0;i<NUM_NODES;i++){
    esp_now_peer_info_t peerInfo = {};
    memcpy(peerInfo.peer_addr, NODE_MACS[i], 6);
    peerInfo.channel = 0;
    peerInfo.encrypt = false;
    if(esp_now_add_peer(&peerInfo) != ESP_OK){
      Serial.println("Failed to add peer");
    }
  }
}

void loop() {
  WiFiClientSecure client;
  client.setInsecure();
  HTTPClient https;
  https.begin(client, String(FIREBASE_URL) + FIREBASE_TOKEN);
  int httpCode = https.GET();

  if(httpCode == 200){
    String payload = https.getString();

    // Parse JSON
    const size_t capacity = 2048;
    DynamicJsonDocument doc(capacity);
    deserializeJson(doc, payload);

    JsonArray docs = doc["documents"].as<JsonArray>();

    // Generate bitmaps per node
    for(int node=0; node<NUM_NODES; node++){
      uint8_t bitmap = 0;
      int start_seat = node*4 + 1;
      int end_seat = start_seat + 3;

      for(JsonObject seat : docs){
        String name = seat["name"].as<String>();
        String seat_number_str = name.substring(name.lastIndexOf("Seat ") + 5);
        int seat_number = seat_number_str.toInt();
        String status = seat["fields"]["status"]["stringValue"].as<String>();

        if(seat_number >= start_seat && seat_number <= end_seat && status == "taken"){
          bitmap |= (1 << ((seat_number-1)%4));
        }
      }

      sendBitmap(NODE_MACS[node], bitmap);
    }

  } else {
    Serial.printf("HTTP GET failed: %d\n", httpCode);
  }
  https.end();

  delay(2000); // poll every 2 seconds
}

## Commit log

2025-07-06 Create sketch.ino for ESP32
    Setup WiFi + supabase, fetch and parse json for interaction with ATtiny2313, early stage
2025-07-06 feat: optimize Supabase fetch with connection reuse and ATtiny LED mapping
    - Added UART setup for ATtiny2313 integration (Serial2 TX pin 17)
    - Implemented connection reuse using http.setReuse(true) to reduce fetch time
    - Parsed Supabase JSON and mapped seat status to 11 ATtiny string arrays
    - Prepared LED status string (4 bits each) to later send over UART
    - Added payload size and timing debug logs
    - Updated loop with 10-second polling interval for lower power consumption
2025-09-23 move bus_main_unit/bus_main_unit.kicad_pcb to hardware/bus_main_unit/bus_main_unit.kicad_pcb
    [bus_main_unit.kicad_pcb]
2025-09-23 move bus_seat_unit/bus_seat_unit.kicad_pcb to hardware/bus_seat_unit/bus_seat_unit.kicad_pcb
    [bus_seat_unit.kicad_pcb]
2025-09-23 move bus_power_unit/bus_power_unit.kicad_pcb to hardware/bus_power_unit/bus_power_unit.kicad_pcb
    [bus_power_unit.kicad_pcb]
